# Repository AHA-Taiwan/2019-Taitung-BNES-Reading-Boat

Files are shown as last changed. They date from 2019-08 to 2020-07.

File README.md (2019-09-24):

# 2019-Taitung-BNES-Reading-Boat

>Humanitarian Architecture in Cambodia<br/>
以台灣國產木材為主體構築材料之人道建築案例，主要材料來源自：行政院農業委員會林務局「台灣木材」標章、臺東林區管理處「香杉」、正昌製材有限公司「台灣杉」、台灣阿克蘇諾貝爾塗料股份有限公司「得利塗料」、東皇昌五金工具有限公司「五金材料」。由交大義築團隊策劃，公東高工家具木工科、南港高工土木科進行實作，規劃設計一個可容納約15名師生使用，離地抬高150公分的閱讀台階及活動平台。<br/>

## 基地環境：<br/>
台灣東南地區，北回歸線以南，有焚風、颱風、東北季風，海風具高度鹽分，設計時需注意材料防潮防蝕保護。<br/>
* 基地環境氣象資料：https://www.cwb.gov.tw/V7/climate/monthlyData/mD.htm <br/>
* 氣象觀測歷史紀錄：https://e-service.cwb.gov.tw/HistoryDataQuery/index.jsp <br/>
* Google Map 位置：https://goo.gl/maps/whQMfPcNdqQ1RDNp8  <br/>

Google Map
***
## 專案介紹：<br/>
* 主要建材：台灣杉[3.8x8.9x360cm]、香杉[直徑27-30cm，長度420cm]、304不鏽鋼M6牙條 [長度100cm]、袋帽、華司、螺母等五金系統。
* 數位模型［整體木構3D］：https://skfb.ly/6MDQK

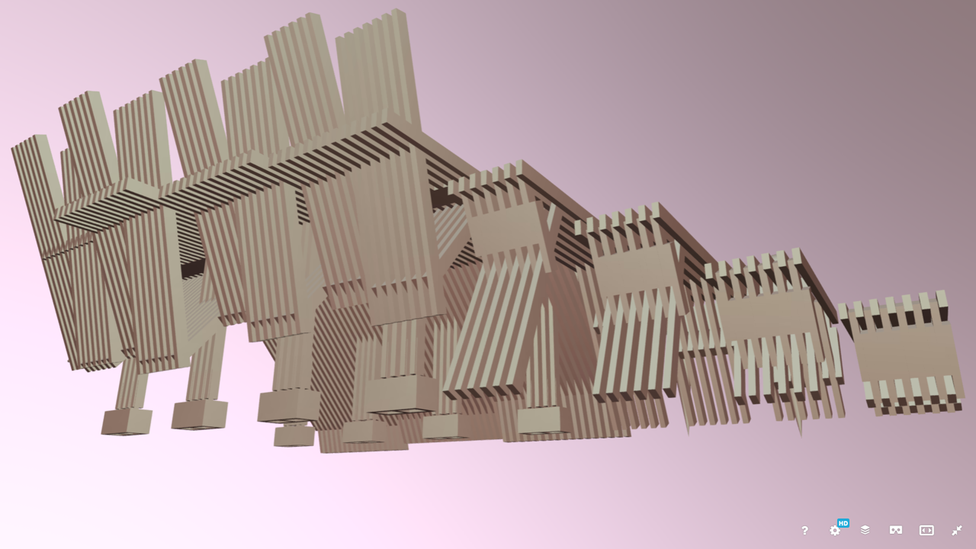
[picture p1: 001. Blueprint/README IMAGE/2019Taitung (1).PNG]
3D Model

<br/>
<br/>
平台工序步驟
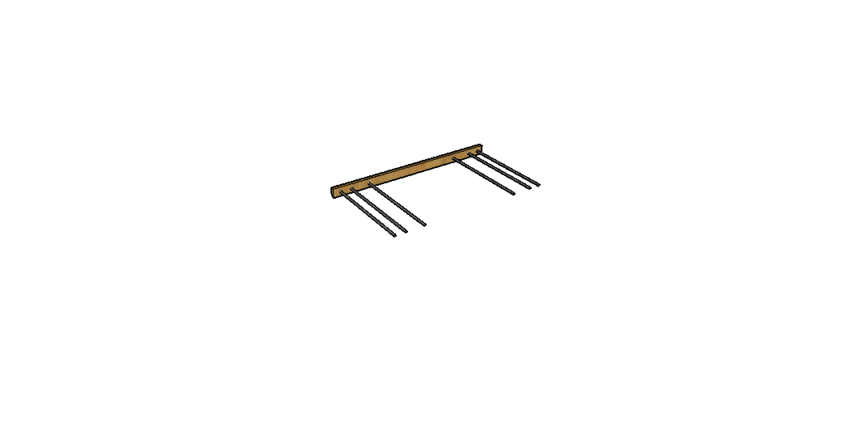
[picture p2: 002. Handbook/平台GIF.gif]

<br/>
<br/>
台階工序步驟
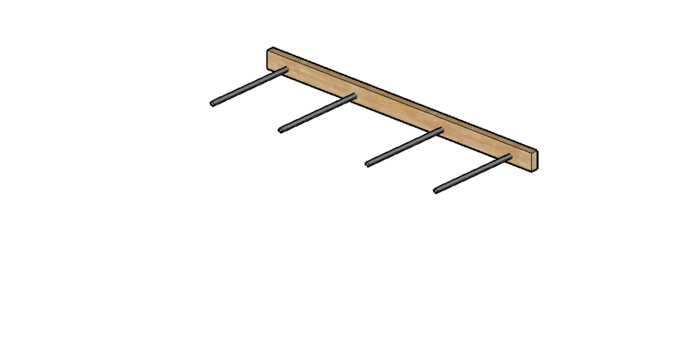
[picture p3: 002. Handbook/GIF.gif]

<br/>
<br/>
***
## 如何達成合作建造：<br/>
* 請參閱［初次合作建造就上手 Collab-Const-Quick-Guide］：<br/>
https://github.com/AHA-Taiwan/Collab-Const-Quick-Guide/wiki <br/>
***
## 確保工作安全：<br/>
* 請參閱［合作建造-安全規範 Collab-Const-Safety］：<br/>
https://github.com/AHA-Taiwan/Collab-Const-Safety/wiki <br/>
***
## 探索合作資源：<br/>
* 請參閱［合作建造-資源探索 Collab-Const-Source］：<br/>
https://github.com/AHA-Taiwan/Collab-Const-Source/wiki <br/>
***
## 取得建造知識：<br/>
* 關於一般的常用構造技術（Techniques），請參閱［合作建造-學習知識 Collab-Const-Learning］：<br/>
https://github.com/AHA-Taiwan/Collab-Const-Learning/wiki <br/>
* 關於本案的特殊構築技術（Tectonic）， 請參閱［本案資料夾 002. Handbook］：<br/>
https://github.com/AHA-Taiwan/2019-Taitung-BNES-Reading-Boat/tree/master/002.%20Handbook <br/>
***

> #### 歡迎參與專案開發，Branch合併可向專案管理者提出請求

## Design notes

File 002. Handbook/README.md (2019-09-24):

Assembly Drawing--組裝爆炸圖<br/>
Assembly-Object Coding--物件編碼表<br/>
Const-Steps GIF--動態組裝圖<br/>
Constr-Process Diagram--建造步驟圖<br/>
Constr-Process Sheet--工項工序表<br/>
Constr-Process PPT--施工簡報<br/>
Constr-Method Photo--現場工法教材>>https://reurl.cc/rlgMRE<br/>

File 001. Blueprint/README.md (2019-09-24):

2D CAD (Site plan)<br/>
2D PDF (2D PNG)<br/>
3D Models (Assembly Drawing & Object)<br/>
3D Pictures (Simulation)<br/>
README IMAGE (Gmap & Sketchfab)<br/>
設計發展 (3D design and development)<br/>

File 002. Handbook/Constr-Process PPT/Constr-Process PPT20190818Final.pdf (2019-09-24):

台階施工SOP | 2019 | 台東義築

卑南國小 閱讀夢公園

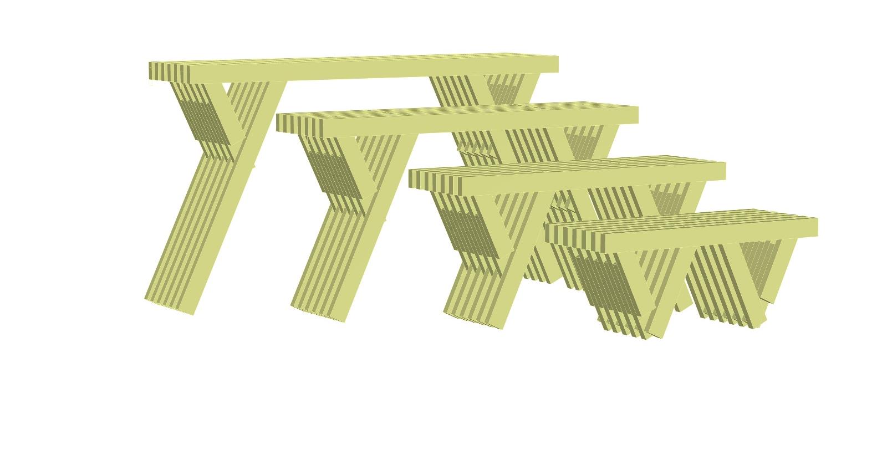
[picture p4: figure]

## 工序 (分三組)

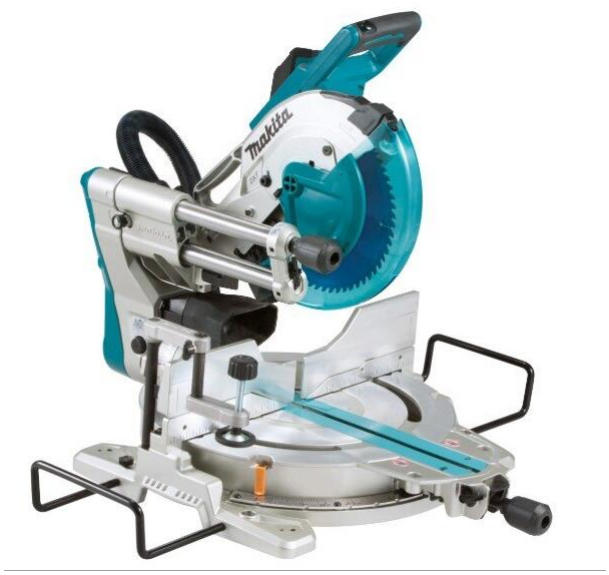
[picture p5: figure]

## 1.尺寸標註&切割 (斬斷機會切掉2mm) 2.打孔(立式鑽床) 3.組裝(穿牙條&鎖牙條)

## 收尾 打磨上漆

# 第一階

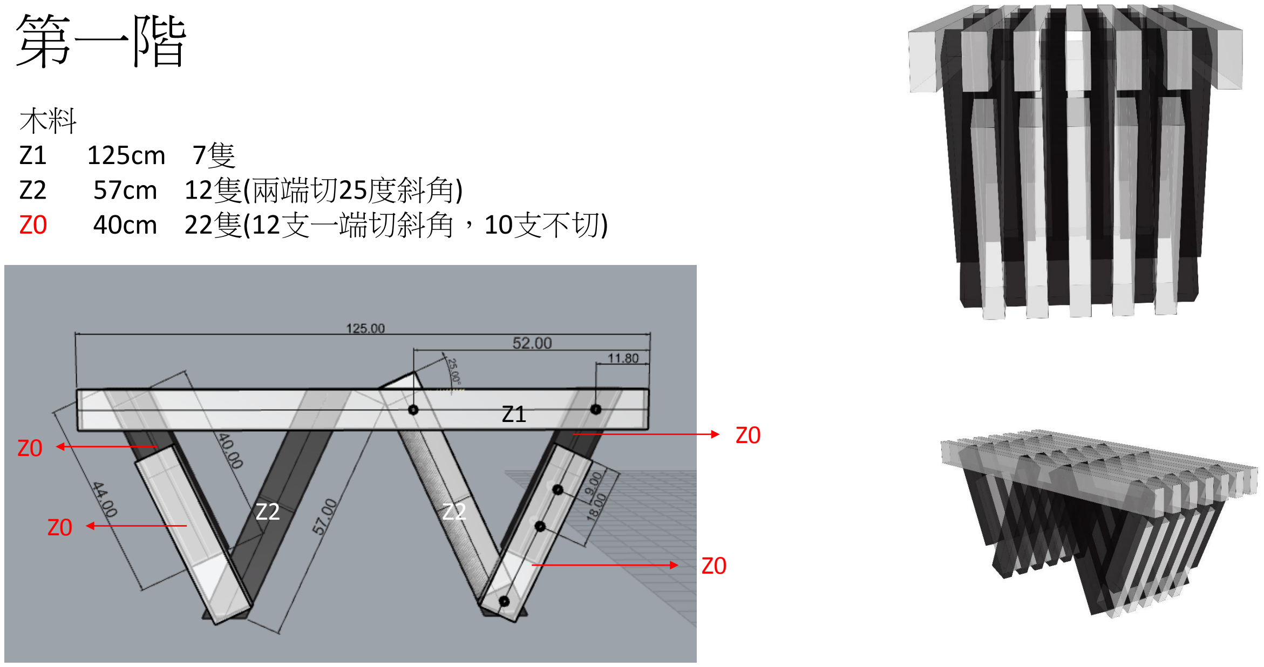
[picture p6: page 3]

木料
Z1 | 125cm 7隻
Z2 | 57cm 12隻(兩端切25度斜角)
Z0 | 40cm 22隻(12支一端切斜角，10支不切)

Z1

Z2 | Z2

Z0

Z0

Z0

Z0

# 鑽孔 (每層台階孔位都相同)

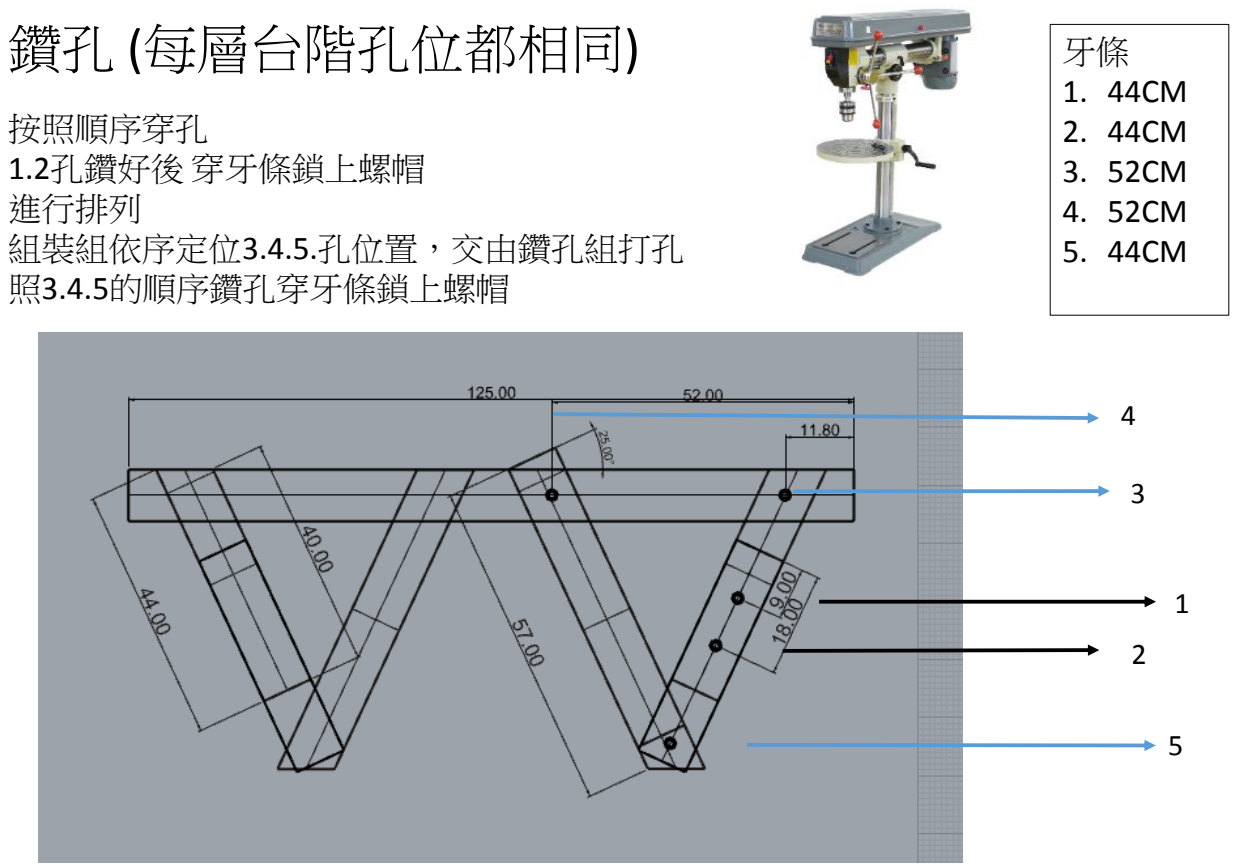
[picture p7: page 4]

按照順序穿孔
1.2孔鑽好後 穿牙條鎖上螺帽
進行排列
組裝組依序定位3.4.5.孔位置，交由鑽孔組打孔
照3.4.5的順序鑽孔穿牙條鎖上螺帽

1
2

3

4

5

牙條
1. 44CM
2. 44CM
3. 52CM
4. 52CM
5. 44CM

# 第二階

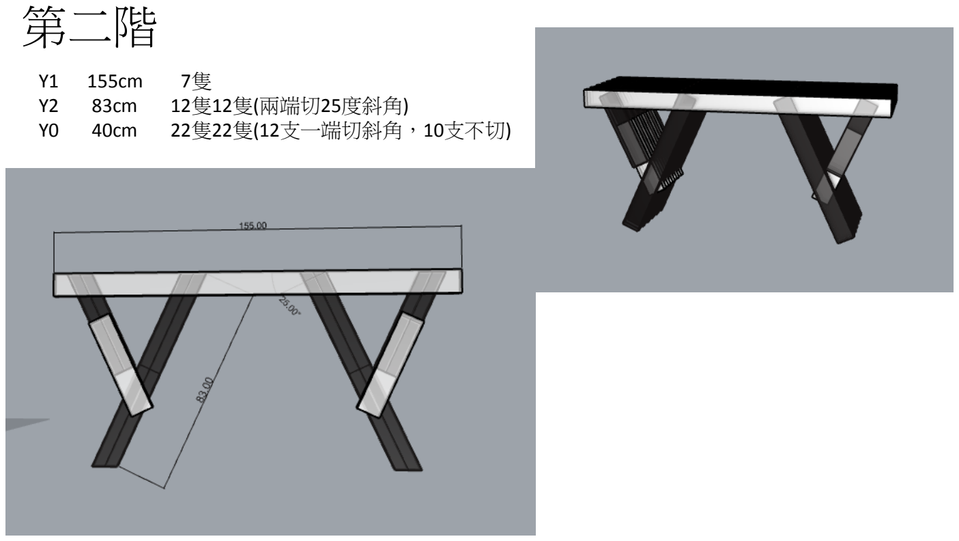
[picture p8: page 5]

Y1 | 155cm | 7隻
Y2 | 83cm | 12隻12隻(兩端切25度斜角)
Y0 | 40cm | 22隻22隻(12支一端切斜角，10支不切)

# 第三階

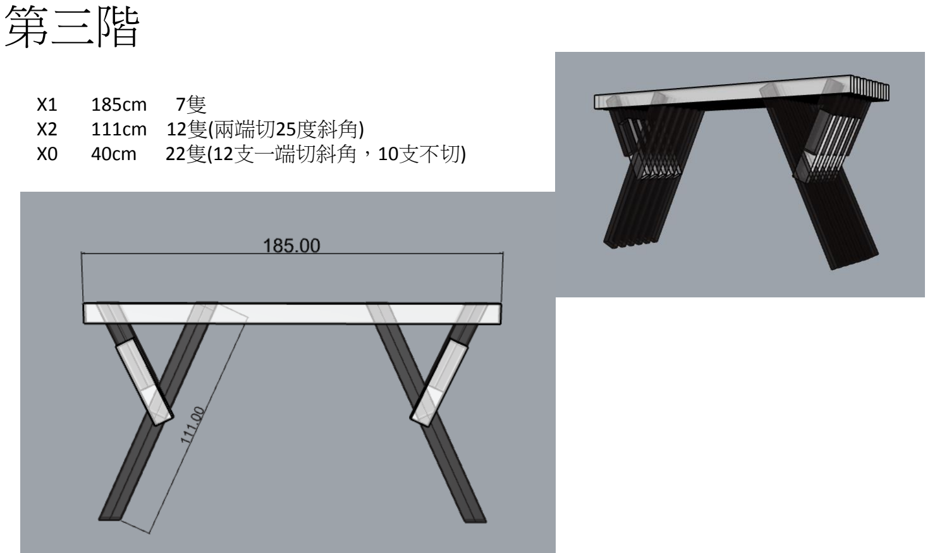
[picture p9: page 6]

X1 | 185cm | 7隻
X2 | 111cm 12隻(兩端切25度斜角)
X0 | 40cm | 22隻(12支一端切斜角，10支不切)

# 第四階

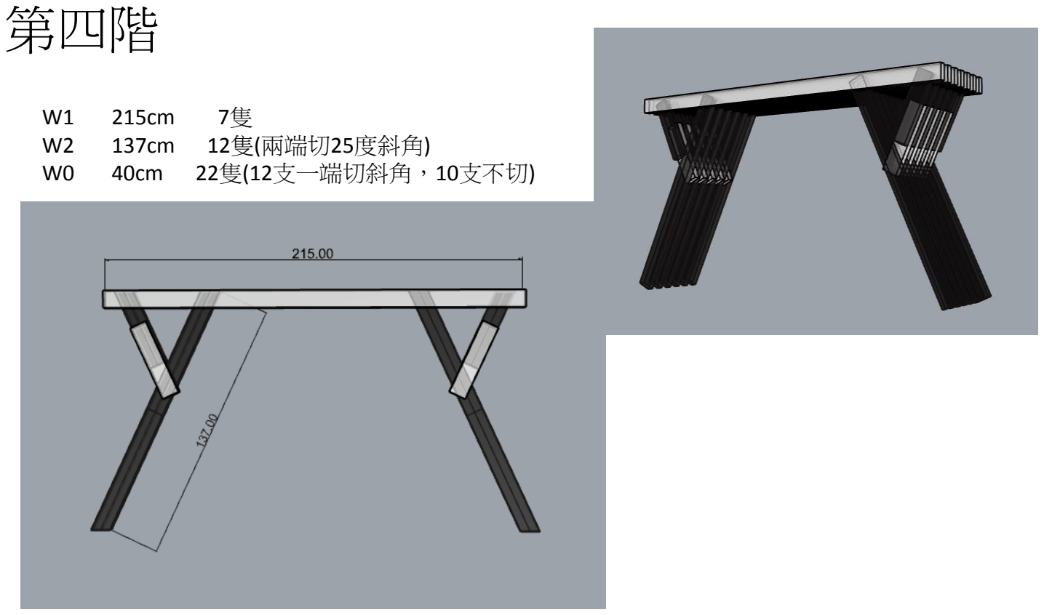
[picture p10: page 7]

W1 | 215cm | 7隻
W2 | 137cm | 12隻(兩端切25度斜角)
W0 | 40cm | 22隻(12支一端切斜角，10支不切)

# END

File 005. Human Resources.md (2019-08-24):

# 專業者佈局與人力成本紀錄 
主要紀錄整體施工過程中，專業者、準專業者、非專業者於不同工項所花費時數，從中可間接推估建造施工人力經費及時間成本。
專業者M、準專業者P、非專業者N，當地人加註C

## 一、台階施工
|人力編碼|當地人|工作總時數(hrs)|請工|換工|志工|
|:-:|:-:|:-:|:-:|:-:|:-:|
|M01 | |12 | | |V |
|M02 | |13 | | |V |
|P01 | |22 | | |V |
|P02 | |22 | | |V |
|P03 | |13 | | |V |
|P04 | |13 | | |V |
|P05 | |13 | | |V |
|P06 | |13 | | |V |
|P04 | |13 | | |V |
|P08 | |13 | | |V |
|P09 | |13 | | |V |
|P10 | |13 | | |V |
***
## 二、平台施工
|人力編碼|當地人|工作總時數(hrs)|請工|換工|志工|
|:-:|:-:|:-:|:-:|:-:|:-:|
|M01 | |50 | | |V |
|M02 | |50 | | |V |
|P01 | |50 | | |V |
|P02 | |50 | | |V |
|P03 | |50 | | |V |
|P04 | |50 | | |V |
|P05 | |50 | | |V |
|P06 | |50 | | |V |
|P04 | |50 | | |V |
|P08 | |50 | | |V |
|P09 | |50 | | |V |
|P10 | |50 | | |V |
***
## 三、基礎施工
|人力編碼|當地人|工作總時數(hrs)|請工|換工|志工|
|:-:|:-:|:-:|:-:|:-:|:-:|
|M01 | |02 | | |V |
|M02 | |02 | | |V |
|P01 | |02 | | |V |
|P02 | |02 | | |V |
|P03 | |02 | | |V |
|P04 | |02 | | |V |
|P05 | |02 | | |V |
|P06 | |01 | | |V |
|P04 | |01 | | |V |
|P08 | |01 | | |V |
|P09 | |01 | | |V |
|P10 | |01 | | |V |
***

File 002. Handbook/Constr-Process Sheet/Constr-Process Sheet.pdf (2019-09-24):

步驟 | 主要工項 | 細項 | 主要材料 | 關鍵工具 | 人力分工 | 專業者 | 準專業者 非專業者 | 工作場地 | Day01. Day02. Day03. Day04. Day05. Day06. Day07. Day08. 1 | 雨備及遮陽 | 帆布臨時支撐 | 廢木條 木工螺絲 | 電動起子 | 3 | 1 | 2 | 0 | D基地 2 | 上帆布 | 帆布 塑膠繩 | 3 | 1 | 2 | 0 | D基地 3 | 木料尺寸及角度標註 | 台灣杉 | 捲尺、直角尺、鉛筆 | 3 | 1 | 2 | 0 | A裁切 4 | 木頭裁切 | 台灣杉 | 斬斷機 | 3 | 0 | 3 | 0 | A裁切 5 | 鑽孔位置標註 | 台灣杉 | 捲尺、直角尺、鉛筆 | 1 | 0 | 1 | 0 | B鑽孔 6 | 台階組裝 | 鑽孔 | 台灣杉 | 立式鑽床(鑽頭1.2cm) | 2 | 0 | 2 | 0 | B鑽孔 7 | 切牙條、磨牙條 | 牙條 | 砂輪機(切、磨) | 1 | 0 | 1 | 0 | A裁切 8 | 組裝 | 螺帽、袋帽、華司 | 鈑手14號 | 4 | 1 | 3 | 0 | C組裝 9 | 洗孔 | 台灣杉 | 立式鑽床(鑽頭4cm) | 2 | 0 | 2 | 0 | B鑽孔
10 | | 打磨 | 台灣杉 | 砂紙(#150,#240)

3

0

3

0 | C組裝
11 | | 木頭尺寸、角度標註 | 台灣杉 | 捲尺、直角尺、鉛筆

3

1

2

0 | A裁切
12 | | 木頭裁切 | 台灣杉 | 斬斷機

3

0

3

0 | A裁切
13 | | 鑽孔位置標註 | 台灣杉 | 捲尺、直角尺、鉛筆

1

0

1

0 | B鑽孔
14 | 平台組裝 | 鑽孔 | 台灣杉 | 立式鑽床(鑽頭1.2cm)
2

0

2

0 | B鑽孔
15 | | 切牙條、磨牙條 | 牙條 | 砂輪機(切、磨)

1

0

1

0 | A裁切
16 | | 組裝 | 螺帽、袋帽、華司 | 鈑手14號

4

1

3

0 | C組裝
17 | | 洗孔 | 台灣杉 | 立式鑽床(鑽頭4cm)

2

0

2

0 | B鑽孔
18 | | 打磨 | 台灣杉 | 砂紙(#150,#240)

3

0

3

0 | C組裝
19 | 上柏油、護木漆 | 上柏油 | 柏油 | 油漆刷 手套
2

0

2

0 | C組裝
20 | | 上護木漆 | 護木漆 | 油漆刷 手套

2

0

2

0 | C組裝
21 | | 放樣 | | 捲尺

2

1

1

0 | D基地
22 | | 挖坑 | | 圓鍬、方鏟、鐵撬

2

0

2

0 | D基地
23 | 基礎&平台安裝 | 拌水泥 | 水泥砂 | 拌漿桶、圓鍬
2

0

2

0 | D基地
24 | 放入平台 定水平 | 水平尺 | 10

1

9

0 | D基地
25 | | 填石頭 | 碎石 | 圓鍬、方鏟

1

0

1

0 | D基地
26 | | 灌水泥 | | 拌漿桶、圓鍬

2

1

1

0 | D基地
27 | | 假支撐 假固定 | 台灣杉、空心磚 | 電動起子

2

1

1

0 | D基地
28 | | 整地 | | 方鏟

2

0

2

0 | D基地
29 | 台階安裝 | 定水平 | | 水平尺
4

1

3

0 | D基地
30 | | 鑽孔 | 台灣杉 | 電動起子(鑽頭1.1cm)

1

1

0

0 | D基地
31 | | 木栓連接 | 木栓(1.0CM) | 鐵鎚

4

1

3

0 | D基地
32 | 連接木條 | 上連接木條 | 木條、木工螺絲 | 電動起子機
3

1

2

0 | D基地
33 | | 上攀爬木條 | 木條、木工螺絲 | 電動起子機

3

1

2

0 D基地

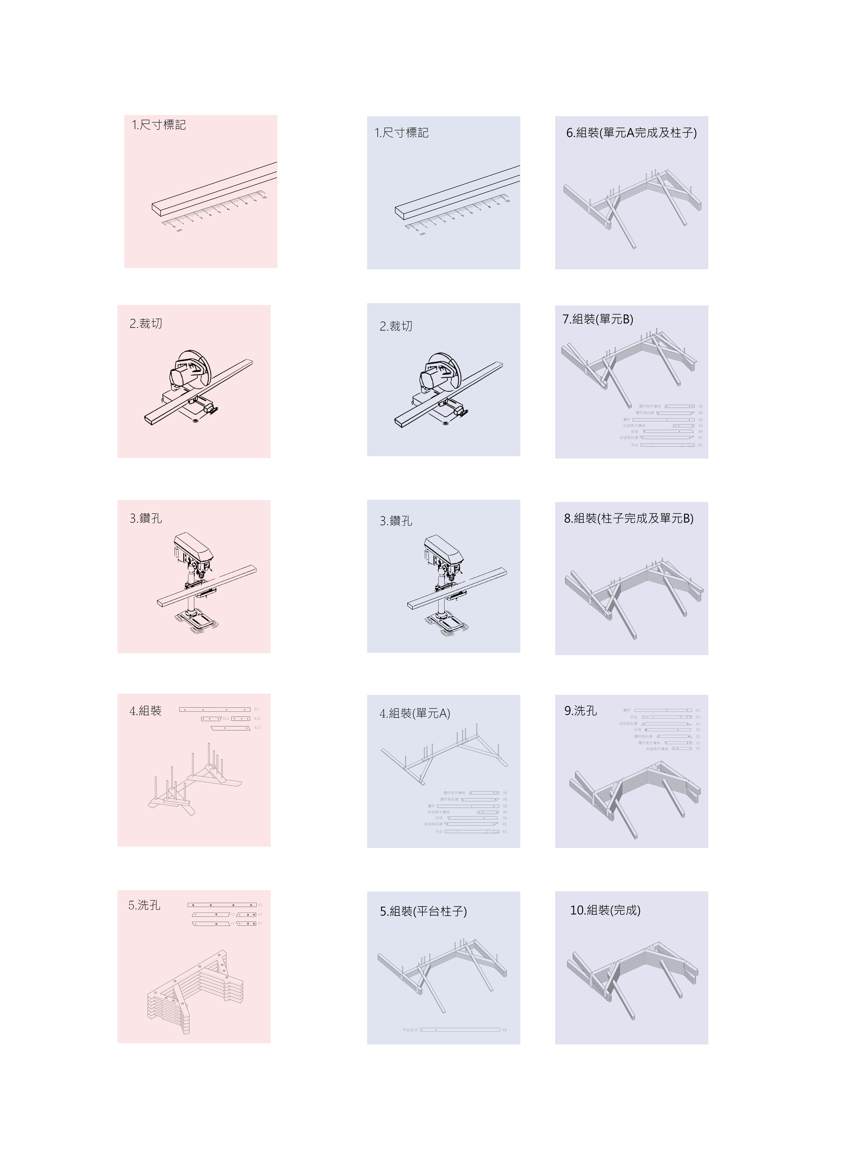
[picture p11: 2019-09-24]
002. Handbook/Constr-Process Diagram/Constr-Process Diagram (1).png

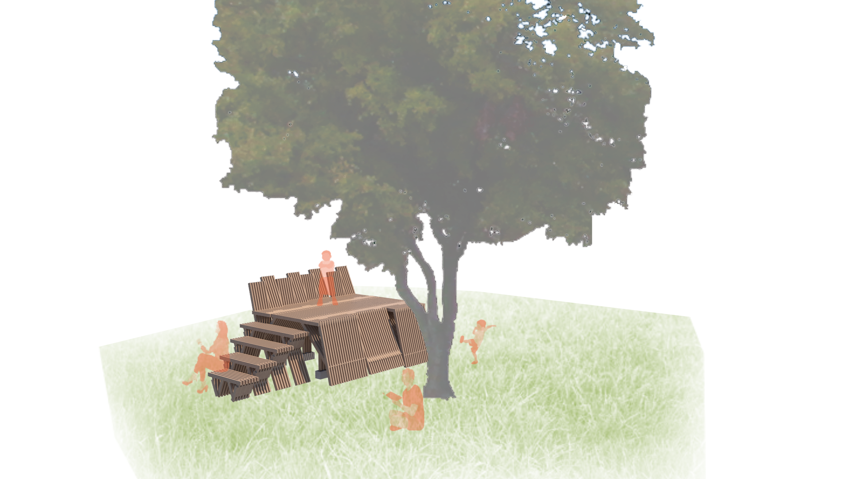
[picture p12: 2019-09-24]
001. Blueprint/3D Pictures/3D Perspective02.png

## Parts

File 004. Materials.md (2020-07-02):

# 材料清單與部件編碼紀錄 
主要紀錄整體施工過程中，各部位構件之材料名稱、規格、數量、單價、材料來源、廠商資訊等，從中可推估材料經費及運輸成本。

## 主要建材（台灣杉）
|編碼|材料名稱|部件位置|規格|單價(元)|數量|材料來源|參考資訊|
|:-:|:-:|:-:|:-:|:-:|:-:|:-:|:-:|
|F001|台灣杉|主體結構|3.8x8.9x360cm|577(含至台東運費)|220|[正昌製材](http://www.wood.jen.com.tw/fengxi/front/bin/home.phtml)|https://www.taiwanwood.org.tw/verify/|
|F002|香杉|台階與攀繩|直徑27-30cm，長度420cm|1,151|4|[台東林區管理處](https://taitung.forest.gov.tw/)|https://www.taiwanwood.org.tw/|
|F003|水泥+砂|基礎|25kg|190|24|[東皇昌](https://www.facebook.com/pages/category/Hardware-Store/%E5%8F%B0%E6%9D%B1-%E6%9D%B1%E7%9A%87%E6%98%8C%E4%BA%94%E9%87%91%E8%A1%8C-296408397206601/)|[嘉宏櫻梅](http://www.yingmei.com.tw/?page_id=4811)|
|F004|空心磚|基礎|一般|100|16|[東皇昌](https://www.facebook.com/pages/category/Hardware-Store/%E5%8F%B0%E6%9D%B1-%E6%9D%B1%E7%9A%87%E6%98%8C%E4%BA%94%E9%87%91%E8%A1%8C-296408397206601/)|http://www.cemestar.com.tw/front/bin/ptdetail.phtml?Part=i-001&Rcg=35159|
|F005|碎石|基礎|2分|150|2|[東皇昌](https://www.facebook.com/pages/category/Hardware-Store/%E5%8F%B0%E6%9D%B1-%E6%9D%B1%E7%9A%87%E6%98%8C%E4%BA%94%E9%87%91%E8%A1%8C-296408397206601/)|https://sites.google.com/site/rtumugongcheng/home/sha-shi|
|F006|特多龍繩|攀爬處|8分|80|2.2kg|[東皇昌](https://www.facebook.com/pages/category/Hardware-Store/%E5%8F%B0%E6%9D%B1-%E6%9D%B1%E7%9A%87%E6%98%8C%E4%BA%94%E9%87%91%E8%A1%8C-296408397206601/)|https://www.andong-plastic.com.tw/product-detail-862379.html|
|F007|柏油|基礎|碳質3加侖9kg|400|2|[東皇昌](https://www.facebook.com/pages/category/Hardware-Store/%E5%8F%B0%E6%9D%B1-%E6%9D%B1%E7%9A%87%E6%98%8C%E4%BA%94%E9%87%91%E8%A1%8C-296408397206601/)|https://zh.wikipedia.org/wiki/%E6%9F%8F%E6%B2%B9|

***
## 五金材料（台東準備）
|編碼|材料名稱|部件位置|規格|單價(元)|數量|材料來源|參考資訊|
|:-:|:-:|:-:|:-:|:-:|:-:|:-:|:-:|
|A001|不鏽鋼牙條|木條間|304不鏽鋼M10長度1M 3/8"|90|5|[東皇昌](https://www.facebook.com/pages/category/Hardware-Store/%E5%8F%B0%E6%9D%B1-%E6%9D%B1%E7%9A%87%E6%98%8C%E4%BA%94%E9%87%91%E8%A1%8C-296408397206601/)|https://reurl.cc/o2lA3|
|A002|不鏽鋼牙條|木條間|304不鏽鋼M10長度1M 3/8"|75|80|[東皇昌](https://www.facebook.com/pages/category/Hardware-Store/%E5%8F%B0%E6%9D%B1-%E6%9D%B1%E7%9A%87%E6%98%8C%E4%BA%94%E9%87%91%E8%A1%8C-296408397206601/)|https://reurl.cc/o2lA3|
|A003|白鐵袋帽|牙條兩端|3/8"|4|140|[東皇昌](https://www.facebook.com/pages/category/Hardware-Store/%E5%8F%B0%E6%9D%B1-%E6%9D%B1%E7%9A%87%E6%98%8C%E4%BA%94%E9%87%91%E8%A1%8C-296408397206601/)|https://reurl.cc/o2lA3|
|A004|白鐵華司|牙條兩端|3/8"(厚1mm)|0.8|280|[東皇昌](https://www.facebook.com/pages/category/Hardware-Store/%E5%8F%B0%E6%9D%B1-%E6%9D%B1%E7%9A%87%E6%98%8C%E4%BA%94%E9%87%91%E8%A1%8C-296408397206601/)|https://reurl.cc/o2lA3|
|A005|白鐵螺母|有洗孔側牙條端|3/8"|1.5|280|[東皇昌](https://www.facebook.com/pages/category/Hardware-Store/%E5%8F%B0%E6%9D%B1-%E6%9D%B1%E7%9A%87%E6%98%8C%E4%BA%94%E9%87%91%E8%A1%8C-296408397206601/)|https://reurl.cc/o2lA3|
***

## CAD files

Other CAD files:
001. Blueprint/2D CAD/Site plan.dwg
001. Blueprint/2D CAD/GL plan.dwg
001. Blueprint/3D Models/0828 3D.skp
001. Blueprint/3D Models/Object definition.skp
001. Blueprint/3D Models/Object length and angle.3dm

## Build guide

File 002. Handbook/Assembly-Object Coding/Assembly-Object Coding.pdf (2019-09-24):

正確的物件尺寸圖【木條、牙條】(台階單元、平台單元)(長度、角度、孔位)

台階 S
1. | S01 | 台階面
2. | SO2 | 台階腳
3. | S03 | 台階斜撐 A
4. | SO4 | 台階斜撐 B
平台
1. | DO1 | 平台
2. | DA1 | 欄杆 A
3. | DA2 | 欄杆側木橫條 A
4. | DA3 | 欄杆側斜撐 A
5. | DA4 | 斜坡 A
6. | DA5 | 斜坡側木橫條 A
7. | DA6 | 斜坡側斜撐 A
8. | DB1 | 欄杆 B
9. | DB2 | 欄杆側木橫條 B
10. DB3 | 欄杆側斜撐 B
11. DB4 | 斜坡
12. DB5 | 斜坡側木橫條 B
13. DB6 | 斜坡側斜撐 B
14. DA7 | 欄杆側柱子 A
15. DA8 | 欄杆側斜撐(有柱洞)A
16. DA9 | 欄杆側木橫條(有柱洞)A
17. DA10 | 斜坡側柱子 A
18. DA11 | 斜坡側斜撐(有柱洞)A
19. DA12 | 斜坡側木橫條(有柱洞)A
20. DB7 | 欄杆側柱子 B
21. DB8 | 欄杆側斜撐(有柱洞)B
22. DB9 | 欄杆側木橫條(有柱洞)B
23. DB10 | 斜坡側柱子 B
24. DB11 | 斜坡側斜撐(有柱洞)B
25. DB12 | 斜坡側木橫條(有柱洞)B

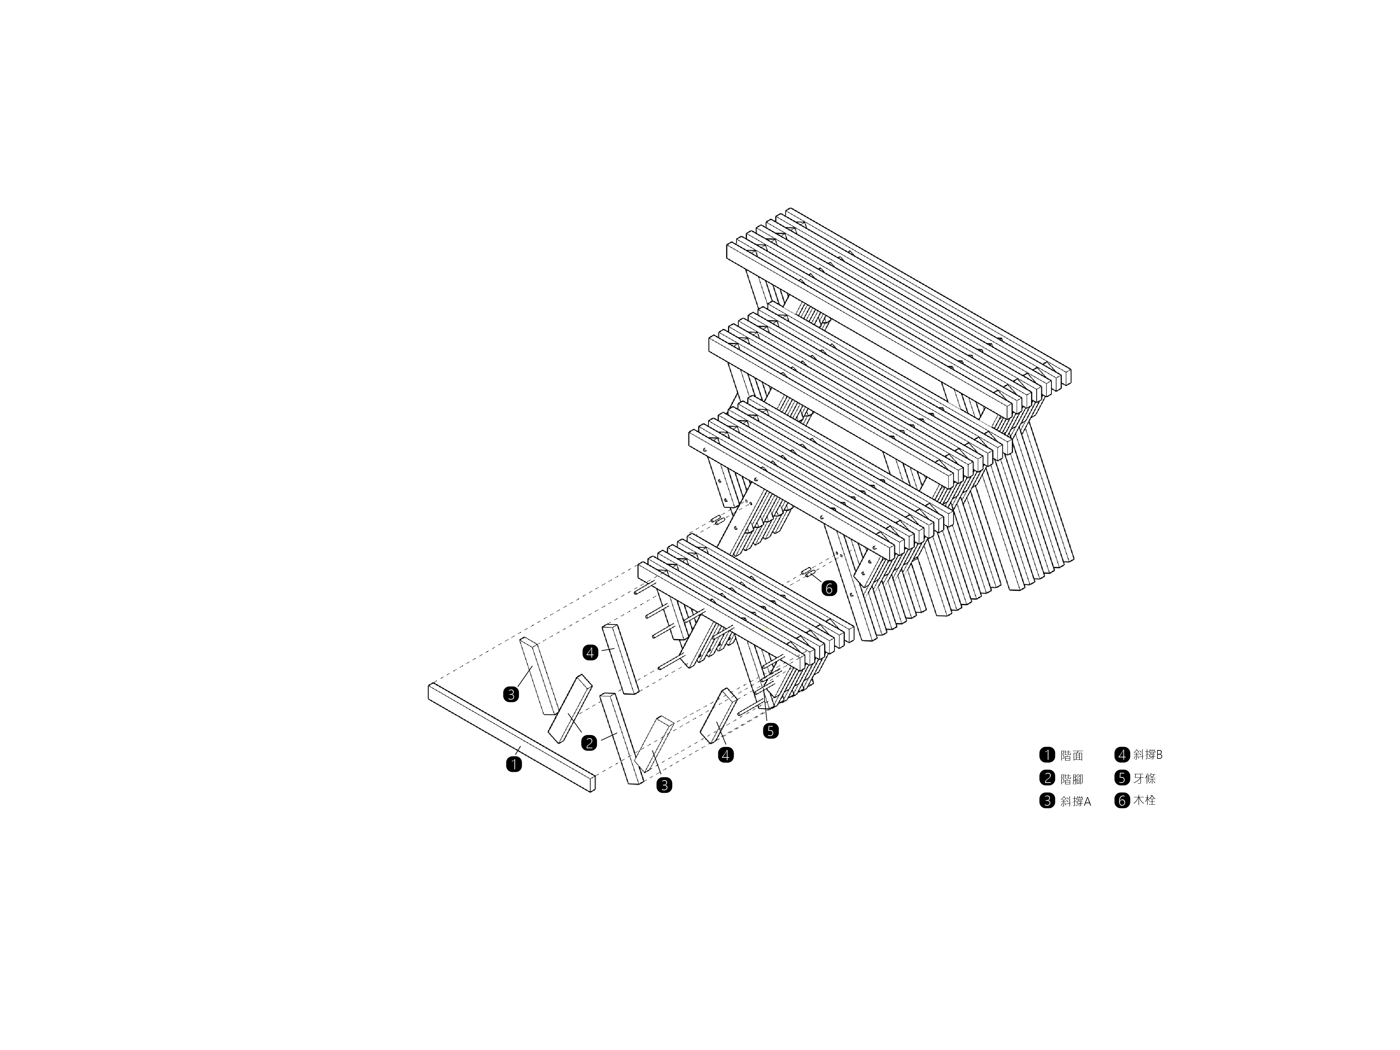
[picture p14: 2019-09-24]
002. Handbook/Assembly Drawing/Assembly Drawing (1).png

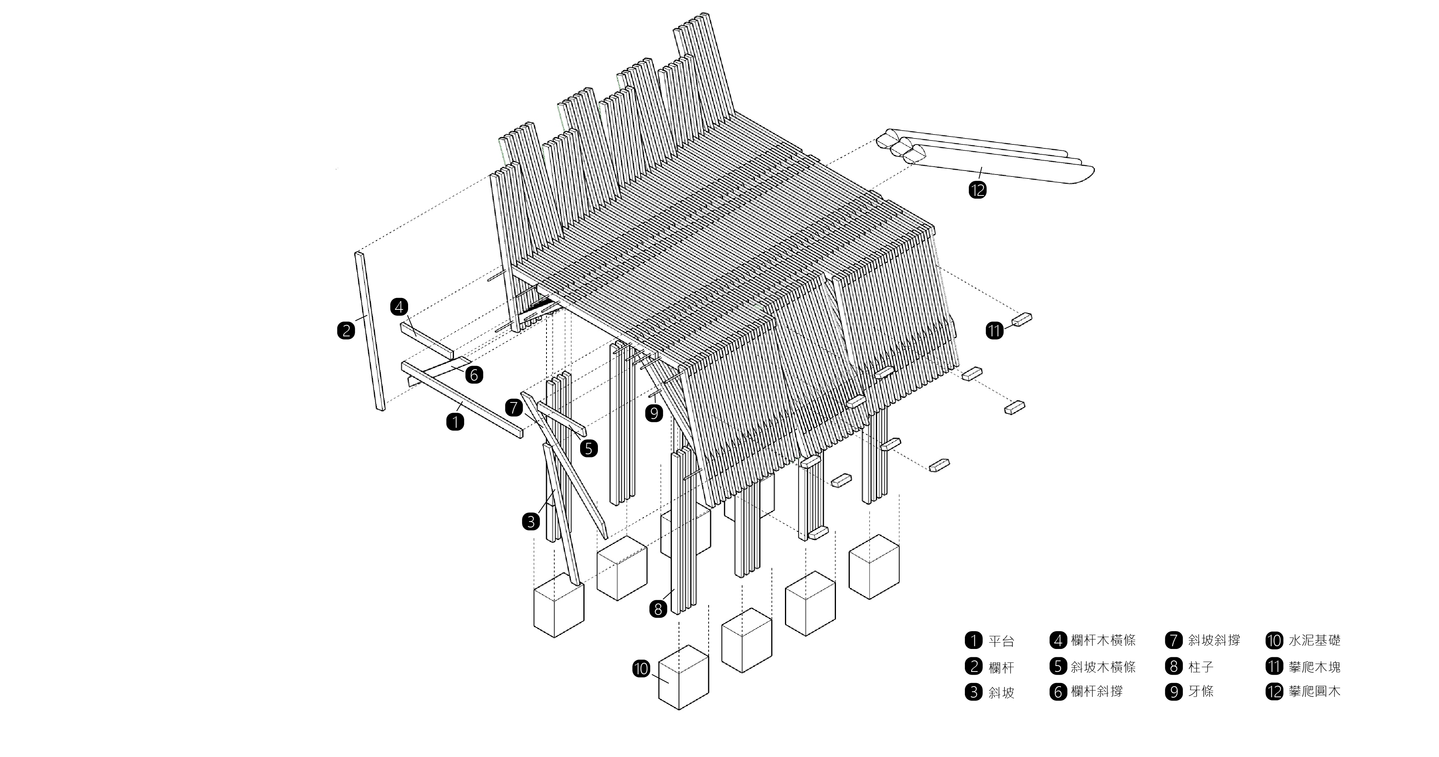
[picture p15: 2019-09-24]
002. Handbook/Assembly Drawing/Assembly Drawing (2).png

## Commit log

2019-08-17 +台階施工PPT
    +台階施工PPT
2019-08-24 Update 004. Materials.md
2019-08-24 +台階gif
    +台階gif
2019-08-24 +平台gif
    +平台gif
2019-09-24 +2D CAD +3D Model
    +2D cad, pdf,
    +3D Models, Pictures
    [0828 3D.skp, GL plan.dwg, Object definition.skp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]
2020-07-02 Update 004. Materials.md
    牙條規格錯誤，M6更正為M10
